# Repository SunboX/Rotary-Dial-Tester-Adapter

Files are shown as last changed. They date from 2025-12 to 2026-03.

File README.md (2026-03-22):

# Rotary Dial Tester Adapter

A small connector/adapter for testing vintage rotary dials (e.g., W48/W49) on a computer. It connects via DB9 RS232 (use an RS232-to-USB adapter) and provides both color-coded screw terminals (GE/GR/BR/WE) and a 4-pin connector for the dial wiring. This repository contains the KiCad project files.

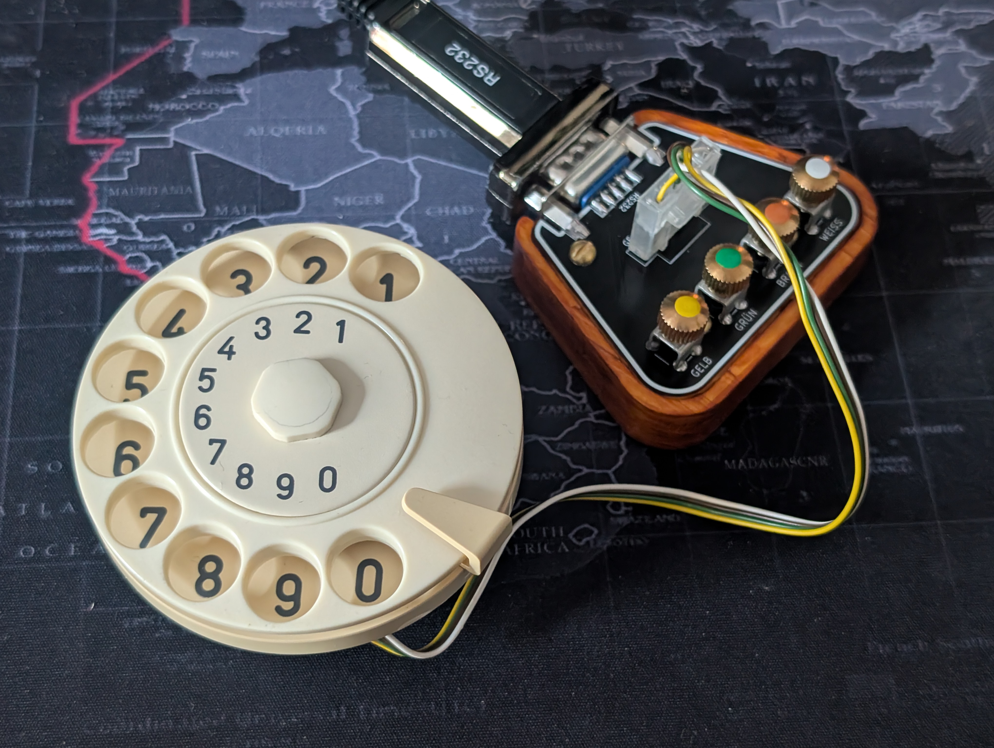
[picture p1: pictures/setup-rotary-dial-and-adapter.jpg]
Rotary dial tester adapter setup


## Overview
- DB9 RS232 interface for USB serial adapters
- Color-coded screw terminals (GE/GR/BR/WE)
- 4-pin connector for a cable harness
- Tested and working with: DIGITUS USB auf Seriell Adapter - RS232 Konverter - USB 2.0 Typ-C zu DSUB 9M - FTDI FT232RL Chipsatz - 1 m Anschlusskabel (https://www.amazon.de/dp/B07917RBBJ)

## Wooden base (CNC)
- Estlcam project: `adapter-wooden-base/Adapter_Base.E12`
- Estlcam is a CAM and CNC control program; offers inexpensive USB control hardware and easy control via gamepads, handwheel pendants, keyboard, and mouse.

## Required materials
- 18 mm wood for the base
- 4x brass wood screws, DIN 96 pan head, slotted, 3 mm x 8 mm
- 4x Keystone Electronics screw terminal 8191-3 (or 7770), M3
- 4x brass knurled screws, M3 x 6 x 9.5
- Adhesive dot set, 5 mm foil K020 (yellow, green, brown, white)
- 4x Wittkower solder terminal, 2.8 mm flat tab, straight, for PCB mounting
- 1x Wurth Elektronik 61800929321, D-SUB receptacle, 9-position, vertical solder

## Wiring
Use either the screw terminals or the 4-pin connector. The wiring diagram below shows the pin mapping.

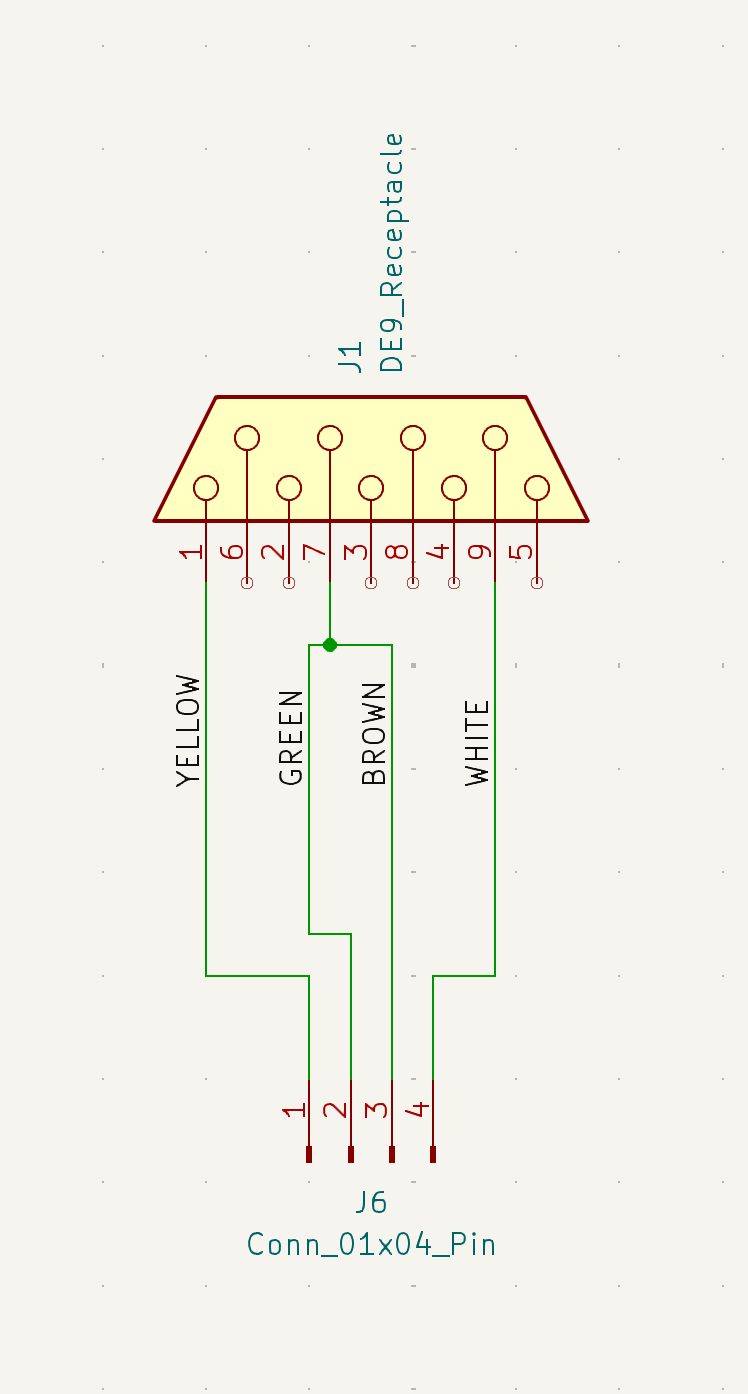
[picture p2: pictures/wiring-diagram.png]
Wiring diagram


### Pinout
- NSI (DCD) -> Yellow (GE) -> SUB-D pin 1
- RTS (common, high) -> Green (GR) + Brown (BR) tied together -> SUB-D pins 2 + 3
- NSA (NSA) -> White (WE) -> SUB-D pin 4
- NSR (DSR) is not connected on this board

NSR (DSR) is the dial’s off-normal/rest contact. It is closed at rest and opens when the dial starts, which can be used to detect start/end of dialing or to mute the speech path during dialing. For simple pulse counting, NSI (DCD) and optionally NSA (RI) are sufficient; if your dial needs NSR, you will need to rewire or modify the adapter.

Non-German rotary dials can be wired differently (e.g., 3-wire Ericsson or some US variants). If your dial needs NSR/DSR, you will need to rewire or modify the adapter, since only DCD/NSI and RI/NSA are routed.

## Web-based Rotary Dial Tester
Project: https://github.com/SunboX/Rotary-Dial-Tester (live: https://rotary-dial-tester.com/)

- Web app using the Web Serial API to read rotary dial pulses.
- Requirements: Chromium-based browser, served over `https://` or `http://localhost`, and a serial adapter that exposes modem status lines (DCD/DSR/RI).
- Signal mapping: nsi = DCD, nsr = DSR, nsa = RI; RTS is set high on connect.
- Usage: Connect COM, Start Test, then dial digits 2-0 (1 is too short for frequency measurement). The browser prompts for the port (no auto-detect).
- Debounce (EP): adds a wait time between DCD reads; higher values can reduce bounce but may affect measurements.
- Analysis: after 10 measurements of the same digit, the app shows runtime spread and pulse/pause tables.

## Photos
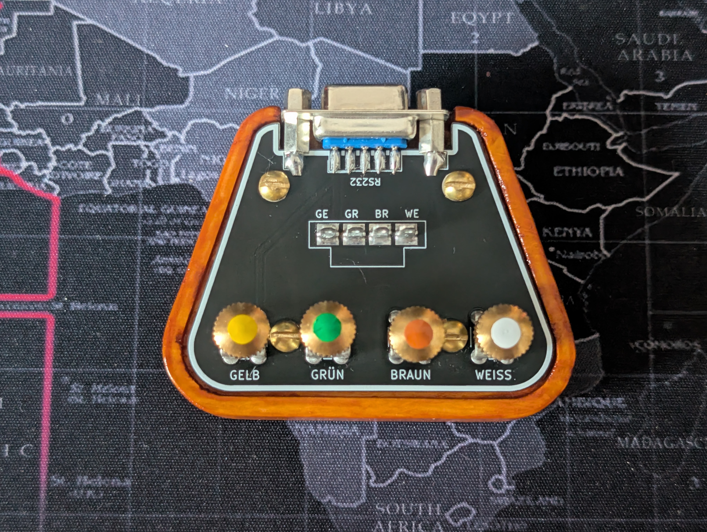
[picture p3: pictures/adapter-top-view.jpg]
Adapter top view

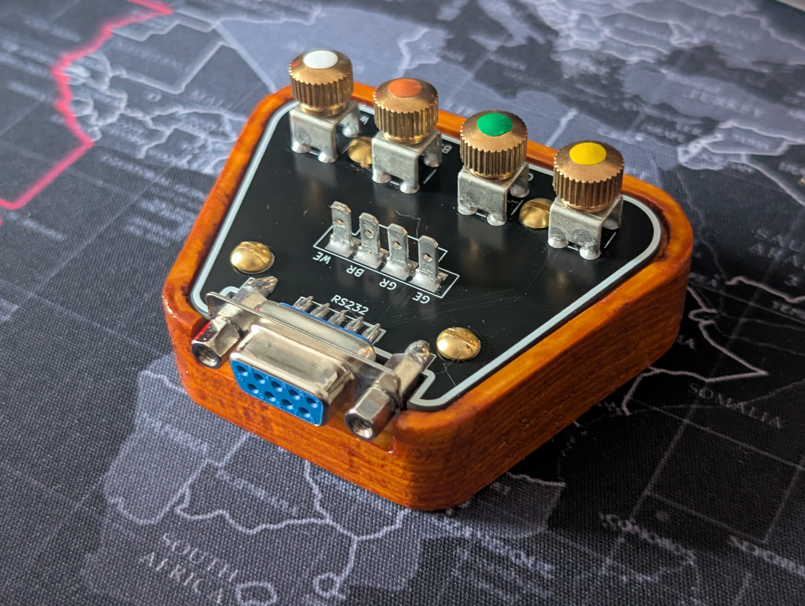
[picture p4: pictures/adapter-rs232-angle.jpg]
Adapter RS232 angle view


## License
This repository is licensed under PolyForm Noncommercial 1.0.0.
See `LICENSE` for the full license text and `NOTICE` for the
required notices that must accompany redistribution.

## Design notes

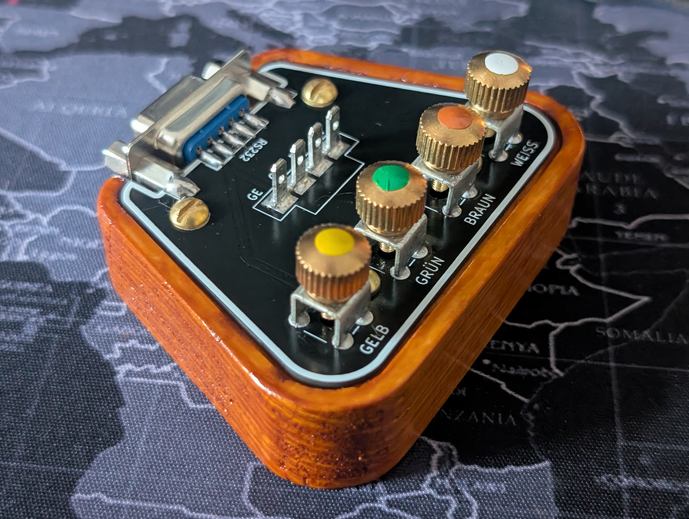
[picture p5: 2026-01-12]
pictures/adapter-top-angle-close.jpg

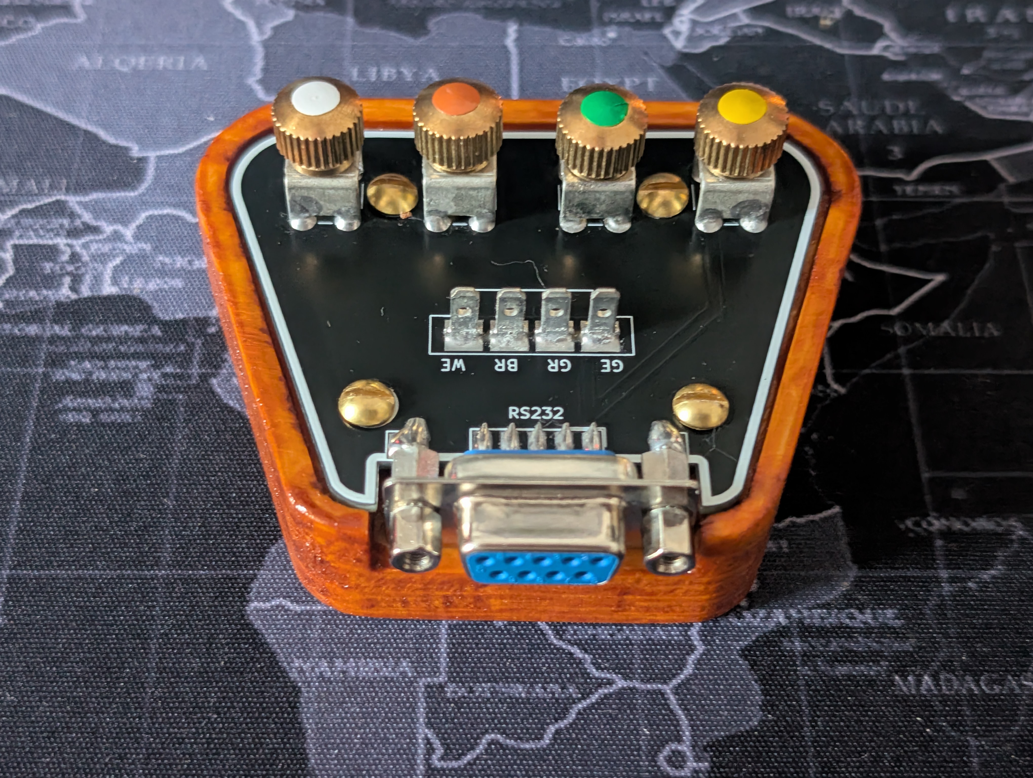
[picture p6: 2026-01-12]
pictures/adapter-rs232-front.jpg

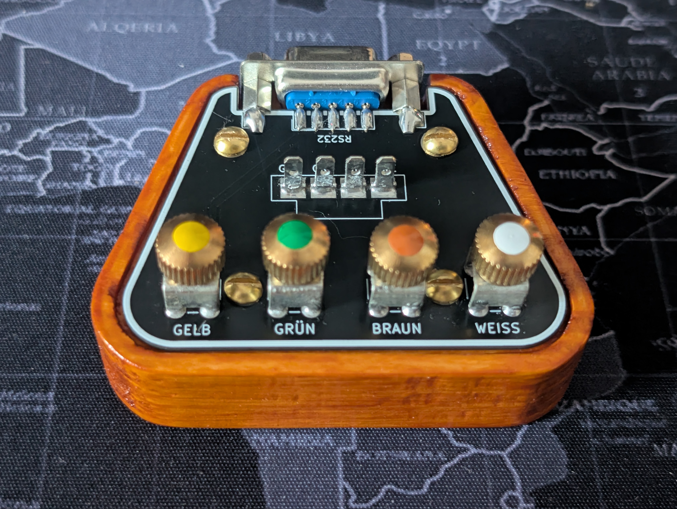
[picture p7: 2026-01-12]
pictures/adapter-top-view-close.jpg

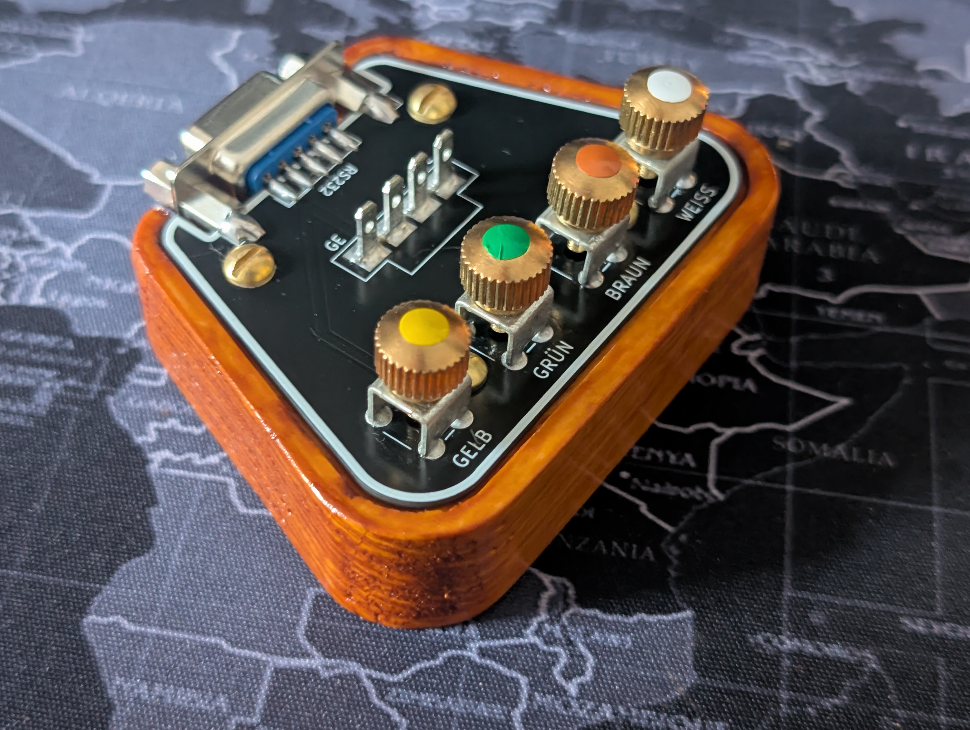
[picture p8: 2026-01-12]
pictures/adapter-top-angle.jpg

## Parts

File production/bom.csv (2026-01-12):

Designator | Footprint | Quantity | Value | LCSC Part #
J1 | DSUB-9_Female_EdgeMount_P2.77mm | 1 | DE9_Receptacle
J2, J3, J4, J5 | KEYSTONE_7770 | 4 | 7770
J6 | PinSocket_1x04_P2.54mm_Vertical | 1 | Conn_01x04_Pin
TP1, TP2, TP3, TP4 | TestPoint_Pad_3.0x3.0mm | 4 | TestPoint

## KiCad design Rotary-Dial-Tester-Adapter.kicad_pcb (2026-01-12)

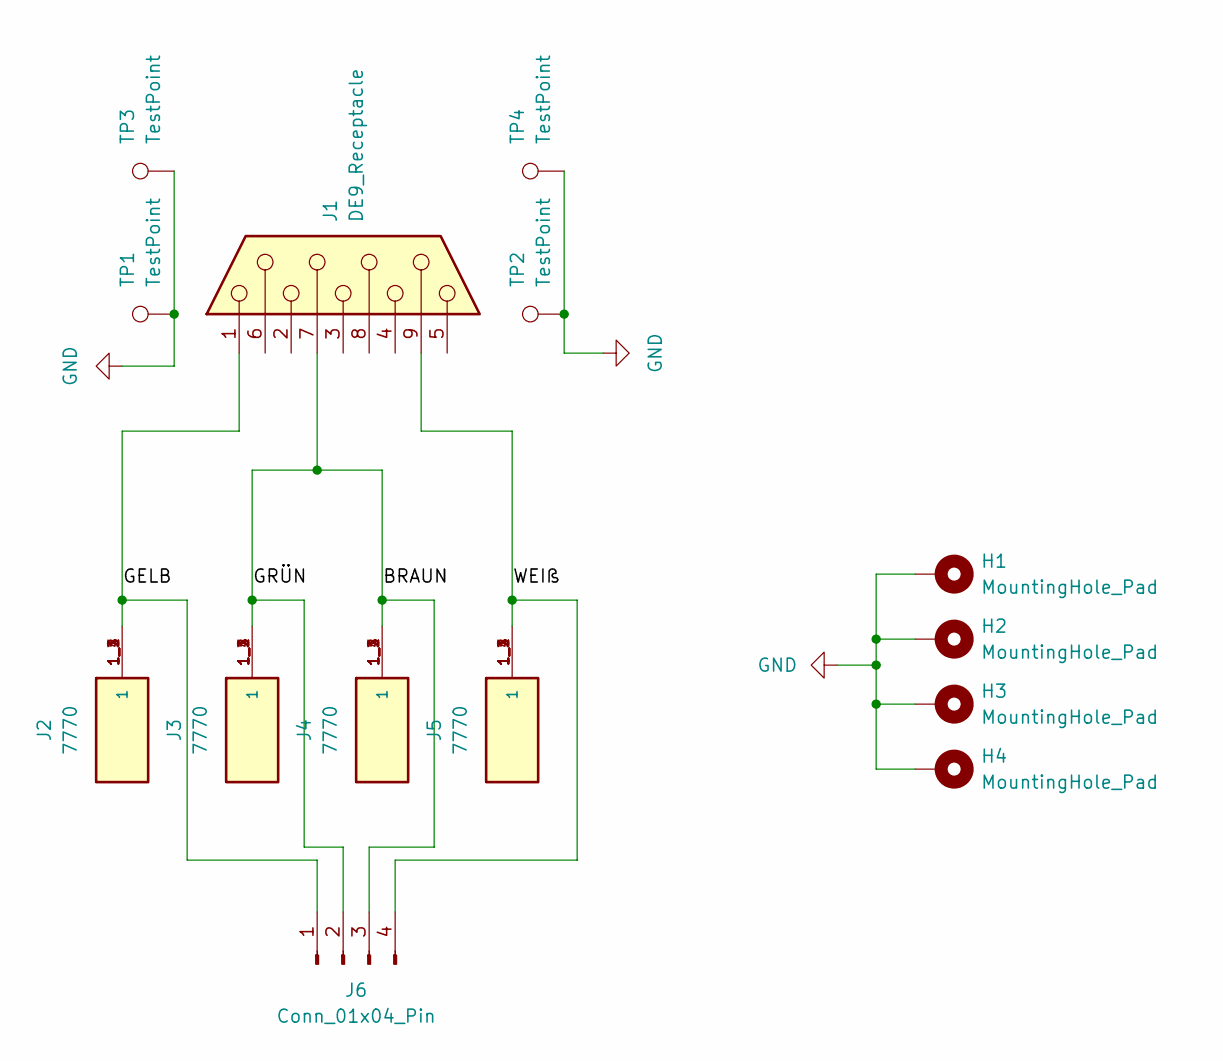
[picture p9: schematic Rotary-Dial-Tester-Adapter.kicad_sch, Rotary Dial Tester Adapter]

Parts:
H1, H2, H3, H4: MountingHole_Pad; MountingHole_3.2mm_M3_DIN965_Pad_TopBottom
J1: DE9_Receptacle; DSUB-9_Female_EdgeMount_P2.77mm
J2, J3, J4, J5: 7770; KEYSTONE_7770; PARTREV B
J6: Conn_01x04_Pin; PinSocket_1x04_P2.54mm_Vertical
TP1, TP2, TP3, TP4: TestPoint; TestPoint_Pad_3.0x3.0mm

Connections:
/BRAUN: J1.7, J3.1_1 (1), J3.1_2 (1), J3.1_3 (1), J3.1_4 (1), J4.1_1 (1), J4.1_2 (1), J4.1_3 (1), J4.1_4 (1), J6.2, J6.3
/GELB: J1.1, J2.1_1 (1), J2.1_2 (1), J2.1_3 (1), J2.1_4 (1), J6.1
/WEIß: J1.9, J5.1_1 (1), J5.1_2 (1), J5.1_3 (1), J5.1_4 (1), J6.4
GND: H1.1, H2.1, H3.1, H4.1, TP1.1, TP2.1, TP3.1, TP4.1

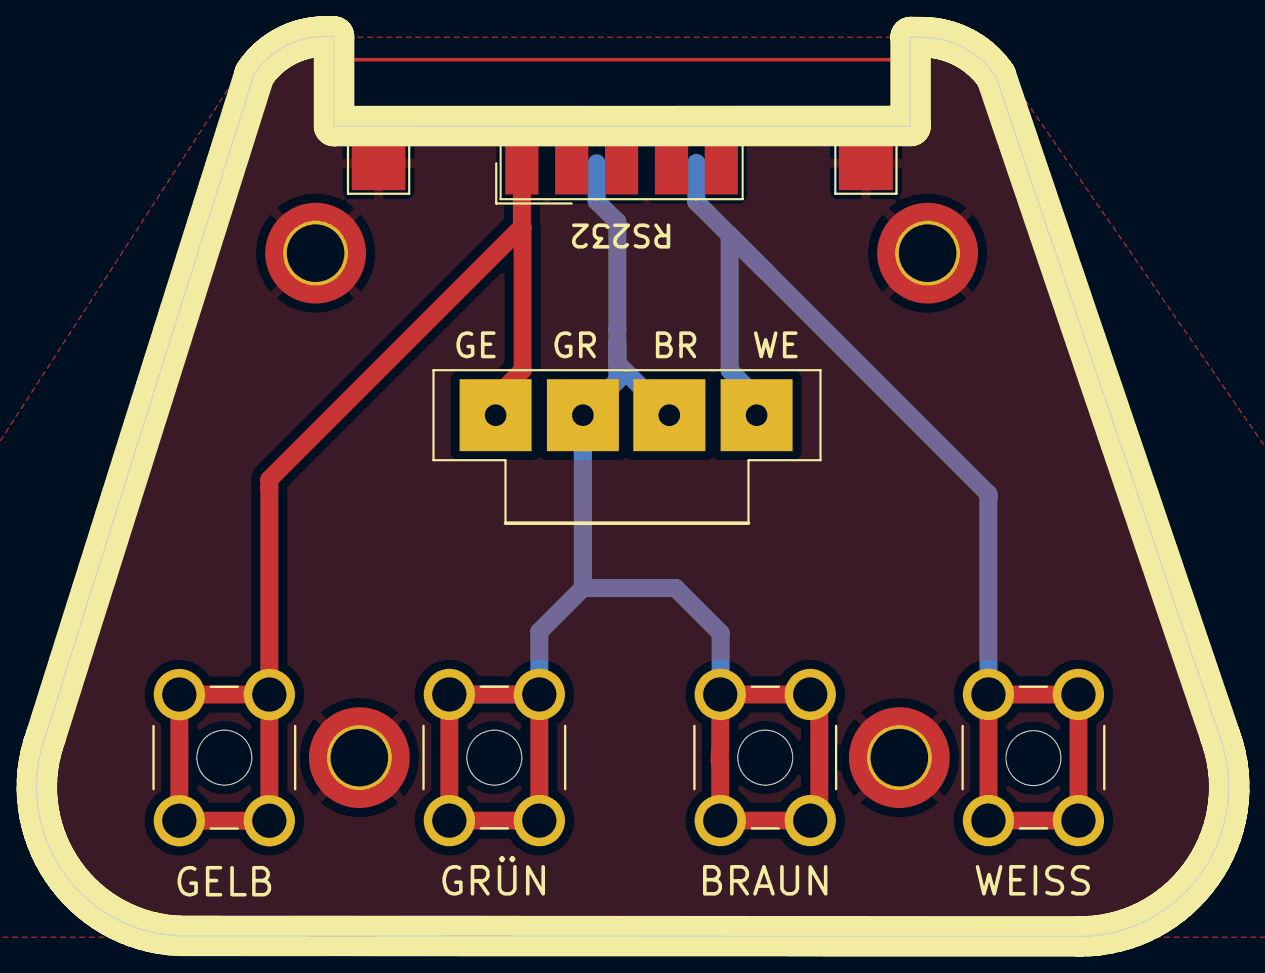
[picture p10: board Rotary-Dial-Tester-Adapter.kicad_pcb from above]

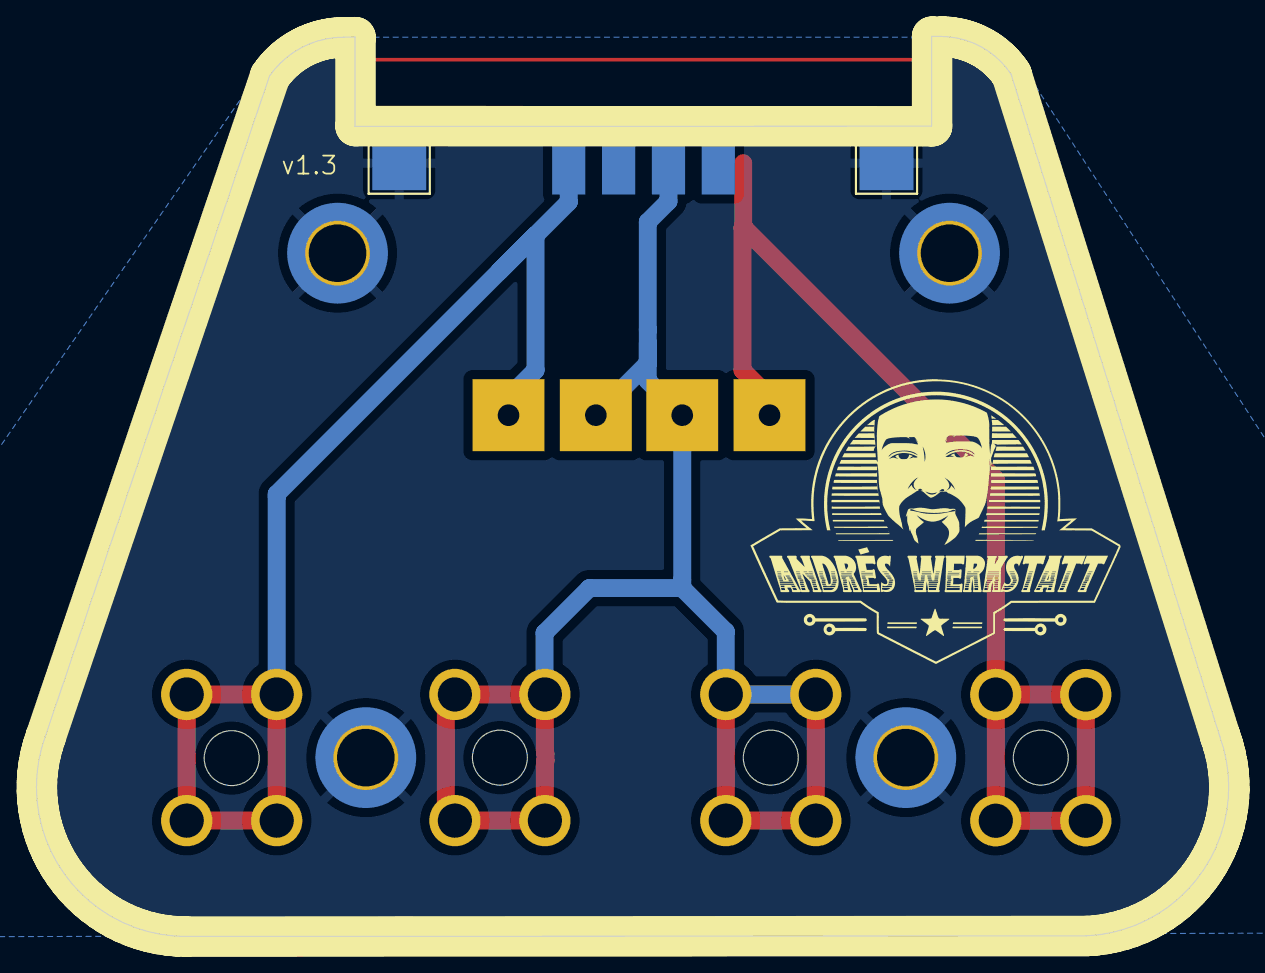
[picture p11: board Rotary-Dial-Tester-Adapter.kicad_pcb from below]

Board: 2 copper layers, 66.2 x 50.0 mm, 14 parts (2 on the bottom side), 4 nets.

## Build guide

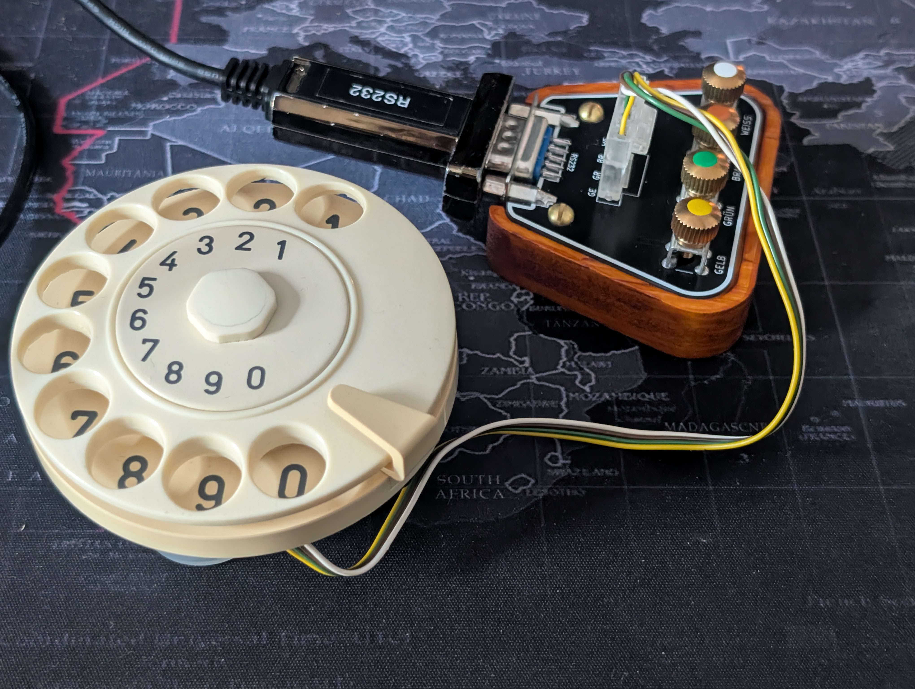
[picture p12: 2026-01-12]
pictures/setup-rotary-dial-and-adapter-side.jpg

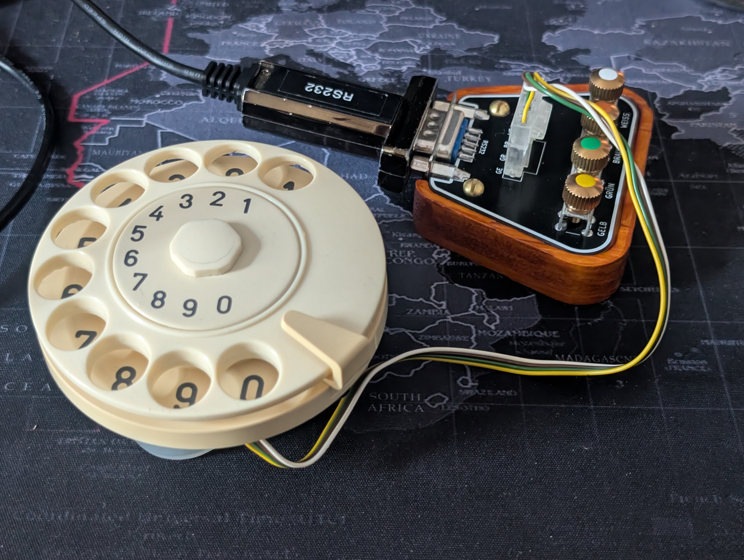
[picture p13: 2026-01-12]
pictures/setup-rotary-dial-and-adapter-cable.jpg

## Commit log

2026-01-12 deleted old project files
    [W48_W49_Nummernschalter_Adapter-B_Cu.gbl, W48_W49_Nummernschalter_Adapter-B_Mask.gbs, W48_W49_Nummernschalter_Adapter-B_Paste.gbp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]
2026-01-12 Migrates project files to graphics/ and renames
    Moves graphic files to the dedicated graphics/ directory.
    Renames main project files for better clarity and consistency,
    reflecting the adapter's purpose.
    Adds a complete project README with wiring diagram
    and project context.
    Adds example photos of wiring and device assembly.
    [Rotary-Dial-Tester-Adapter.kicad_pcb, Rotary-Dial-Tester-Adapter.kicad_sch]
2026-01-12 Adds project license and metadata
    Adds a "Permission Required License" and copyright notice.
    Updates the schematic and PCB files to include a title block with project metadata and license information.
    This ensures proper attribution and clarifies usage restrictions.
    [Rotary-Dial-Tester-Adapter.kicad_pcb, Rotary-Dial-Tester-Adapter.kicad_sch]
2026-01-12 Adds initial fabrication toolkit files
    Adds necessary files for the fabrication toolkit,
    including options, BOM, designators, netlist,
    component positions, and production archives.
    [bom.csv, designators.csv, positions.csv]
2026-01-13 Increases solder mask clearance
    Increases the solder mask to copper clearance value.
    This adjustment improves manufacturability by providing a small buffer between the solder mask and copper features, reducing the risk of solder mask encroachment.
2026-01-13 Clarifies project purpose in README
    Adds a sentence to the README to explicitly state that the
    repository contains the KiCad project files for the rotary dial tester.
2026-01-13 Enhances README with additional details on Estlcam control options and required materials for the wooden base
2026-01-13 Updates required materials in README to correct screw terminal part number
2026-01-13 Clarifies required materials in README by specifying alternative part number for screw terminal
2026-01-15 Adds detailed pinout information and wiring notes for rotary dials in README

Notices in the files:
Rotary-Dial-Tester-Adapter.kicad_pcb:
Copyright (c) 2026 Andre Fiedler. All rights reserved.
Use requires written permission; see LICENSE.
